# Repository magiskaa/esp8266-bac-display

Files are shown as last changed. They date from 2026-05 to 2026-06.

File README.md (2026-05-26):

# ESP8266 BAC Display

This displays the BAC of a chosen user from the [telegram bot](https://github.com/magiskaa/telegram-bot). It can also add a drink in the [telegram bot](https://github.com/magiskaa/telegram-bot) with a button.

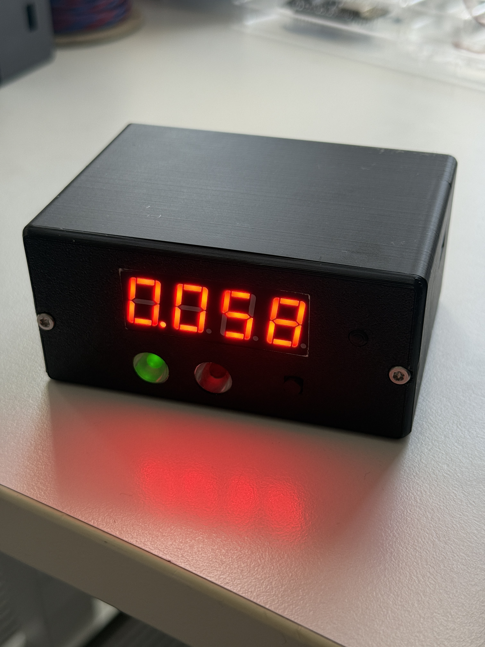
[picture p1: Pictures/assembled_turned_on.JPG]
BAC Display


## Hardware

- Microcontrollers (ESP8266MOD 12-F and Arduino Nano)
- 4-digit 7-segment display
- A green and a red LED
- Two 220Ω resistors
- 4-pin pushbutton
- Jumper wires
- 3D-printed case
- Two M3 threaded inserts and two M3x10 screws

Wiring references:

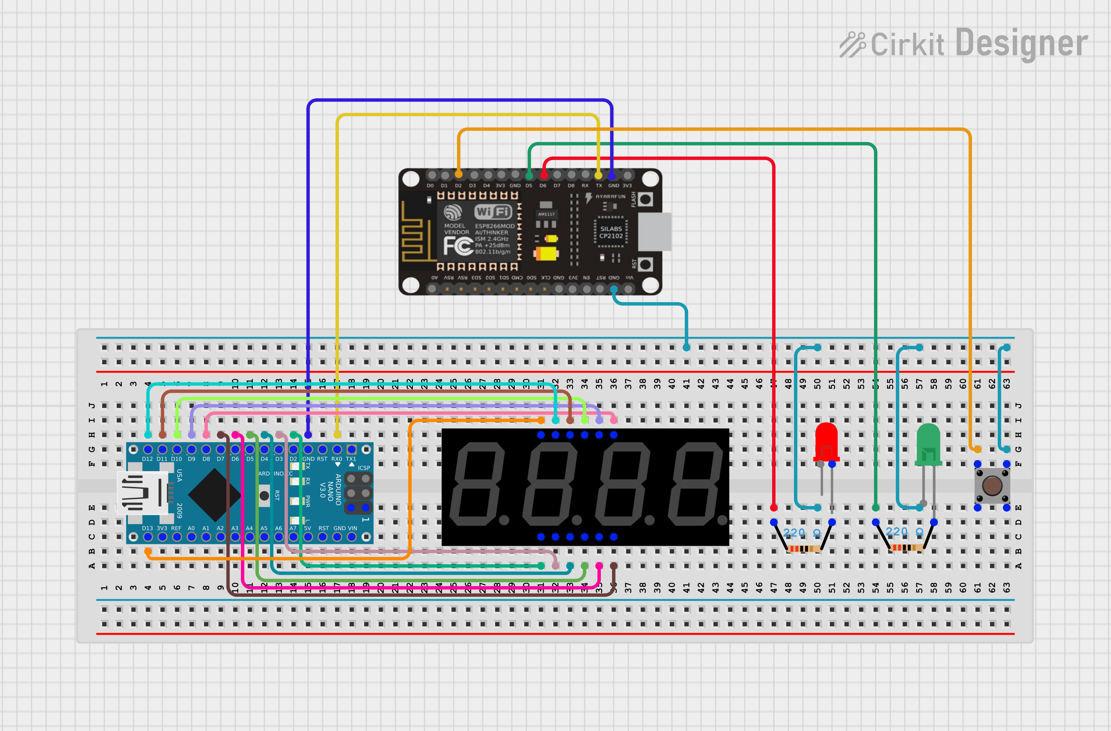
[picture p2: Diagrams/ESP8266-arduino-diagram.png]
ESP8266 BAC Display
- ESP8266 & Arduino Nano & 7-segment display 

## secrets.h

Path to secrets-file: `Sketches/secrets.h`

```cpp
#ifndef SECRETS_H
#define SECRETS_H

const char* SSID = "WIFI_SSID";
const char* PASSWORD = "WIFI_PASSWORD";

const char* SERVER_NAME_BAC = "http://IP_ADDRESS:PORT/PATH";
const char* SERVER_NAME_DRINK = "http://IP_ADDRESS:PORT/PATH";

const char* USER_ID = "TELEGRAM_USER_ID";

#endif
```

## License

This project is licensed under the MIT License (see `LICENSE`).

## Contact

**Valtteri Antikainen**
vantikaine@gmail.com

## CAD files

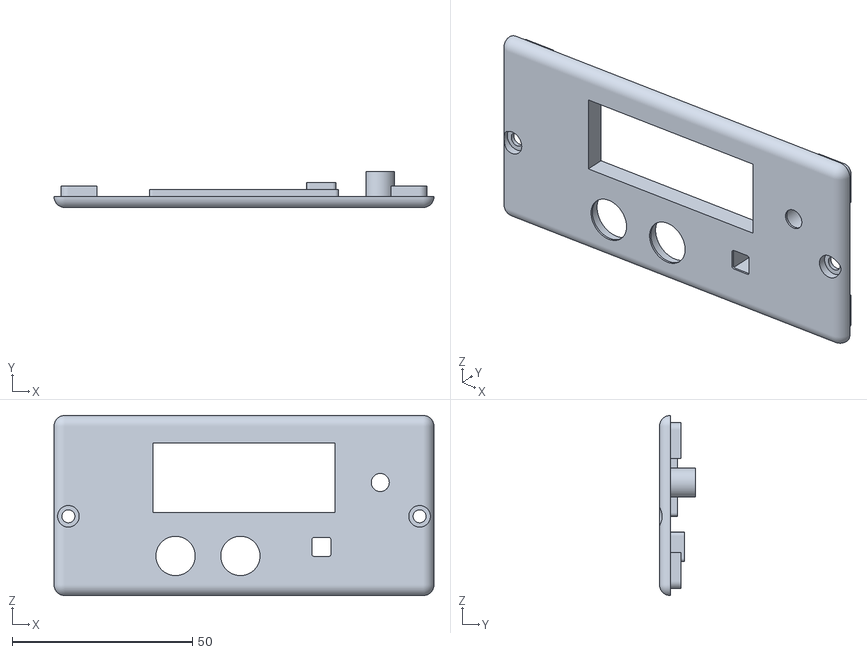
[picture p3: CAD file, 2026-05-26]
3D-models/STL-files/lid.stl
105.5 x 10.0 x 50.0

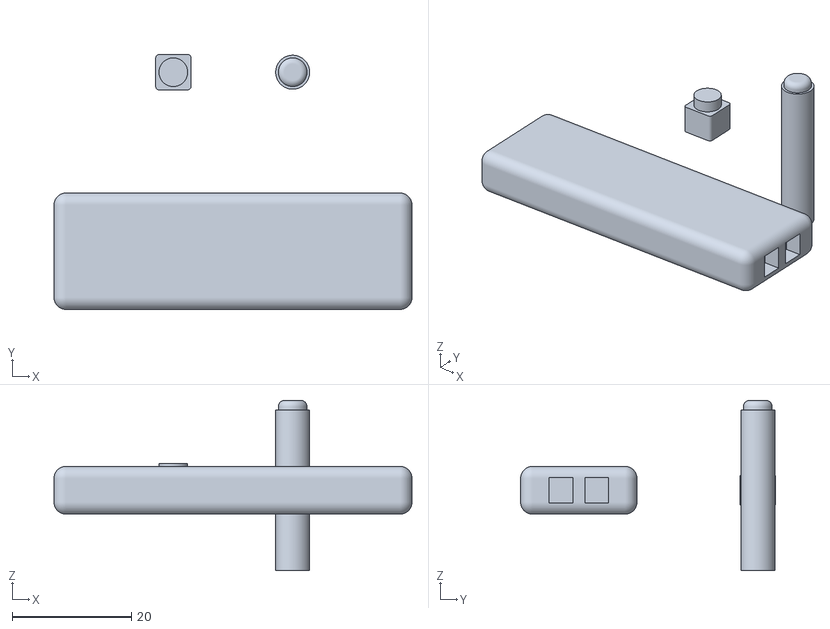
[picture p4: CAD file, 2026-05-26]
3D-models/STL-files/button_rods.stl
60.0 x 42.7 x 28.5

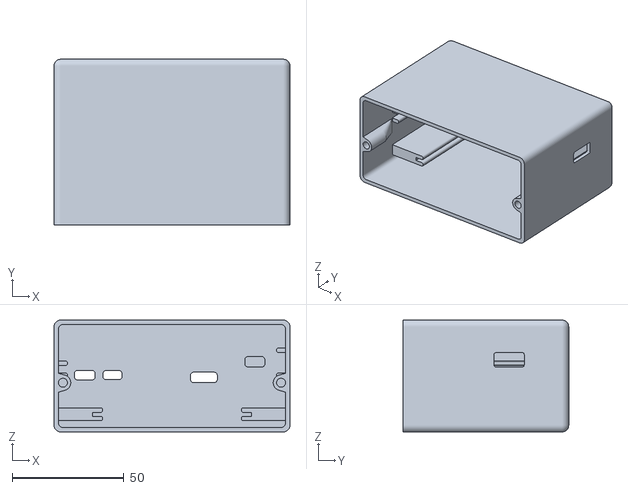
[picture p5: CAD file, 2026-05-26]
3D-models/STL-files/case.stl
105.5 x 74.0 x 50.0

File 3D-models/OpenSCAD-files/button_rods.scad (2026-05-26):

include <BOSL2/std.scad>

rod_r = 2.4;
rod_side = 6.1 - 0.2;
rod_h = 5;

pwr_rod_r = 2.85;
pwr_rod_h = 26.9;
pwr_rod_r_small = 2.4;


$fn = 100;

left(10)
cuboid([rod_side, rod_side, rod_h], rounding = 0.5, edges = "Z") {
	position(TOP) zcyl(r = rod_r, h = 2, anchor = BOTTOM);
}

right(10)
zcyl(r = pwr_rod_r, h = pwr_rod_h) {
	position(TOP) zcyl(r = pwr_rod_r_small, h = 1.6, anchor = BOTTOM, rounding2 = 1);
}

diff() {
	fwd(30)
	cuboid([60, 19.5, 8], rounding = 2) {
		yflip_copy(offset = 0)
		tag("remove") position(RIGHT) fwd(3) cuboid([6, 4, 4.2]);
	}
}

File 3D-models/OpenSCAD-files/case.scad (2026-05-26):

include <BOSL2/std.scad>

wall_t = 2;

w = 101.5;
d = 72;
h = 46;

$fn = 100;

diff() {
	cuboid([w + 2*wall_t, d + wall_t, h + 2*wall_t], rounding = 3, edges = ["Y", BACK]) {
		tag("remove") fwd(wall_t / 2 + 0.001) cuboid([w, d, h], rounding = 2, edges = "Y");
		
		// USB PORT
		up(h / 2 - 21.6 + 9) back((d-wall_t) / 2 - 17.9)
		tag("remove") position(RIGHT) cuboid([5, 13.5, 6.3], anchor = TOP+BACK, rounding = 0.75, edges = "X");
		
		up(h / 2 - 21.6 + 2.6) right(w / 2 - 9.2) fwd(3)
		tag("remove") position(BACK) cuboid([9, 5, 4.7], anchor = BOTTOM+RIGHT, rounding = 1.5, edges = "Y");

		// BATTERY CHARGE INDICATOR
		up(h / 2 - 21.6 + 2.8 - 7.2) right(w / 2 - 30.5)
		tag("remove") position(BACK) cuboid([12, 5, 4.7], anchor = BOTTOM+RIGHT, rounding = 1.5, edges = "Y");
		
		// BATTERY SHIELD PORTS
		up(h / 2 - 21.6 + 1.1) left(w / 2 - 7.1)
		tag("remove") position(BACK) cuboid([9.3, 5, 4.3], anchor = TOP+LEFT, rounding = 1.5, edges = "Y");
		
		up(h / 2 - 21.6 + 1) left(w / 2 - 19.8)
		tag("remove") position(BACK) cuboid([8.7, 5, 4], anchor = TOP+LEFT, rounding = 1.5, edges = "Y");
		
		// ESP & ARDUINO PORTS
//		down(h / 2 - 5 - 6.6) left(70 / 2 - 22.3)
//		tag("remove") position(BACK) cuboid([8.7, 5, 4], rounding = 1.5, edges = "Y");
//		
//		down(h / 2 - 5 - 6.6 - 1.5) right(70 / 2 - 16)
//		tag("remove") position(BACK) cuboid([9.3, 5, 4.3], rounding = 1.5, edges = "Y");
	}	
}

xflip_copy(offset = 0)
right(w/2-wall_t) fwd((d+wall_t)/2-6) down(3)
diff() {
	hull() {
		ycyl(r = 3.5, h = 12);
		
		right(3.5) back(7) cuboid([1, 26, 9]);
	}
	
	tag("remove") ycyl(r = 2, h = 12.01);
}

// BATTERY

xflip_copy(offset = 0)
up(h / 2 - 21.6) left(w / 2) back((d-wall_t) / 2)
cuboid([4, 48, 2], anchor = TOP+LEFT+BACK, rounding = 0.8, edges = RIGHT, except = [BACK, FRONT]);

up(h / 2 - 21.6 + 3.3) left(w / 2) back((d-wall_t) / 2)
cuboid([4, 48, 2], anchor = BOTTOM+LEFT+BACK, rounding = 0.8, edges = RIGHT, except = [BACK, FRONT]);

up(h / 2 - 21.6 + 9.1) right(w / 2) back((d-wall_t) / 2)
cuboid([4, 48, 2], anchor = BOTTOM+RIGHT+BACK, rounding = 0.8, edges = LEFT, except = [BACK, FRONT]);


// ESP & ARDUINO

xflip_copy(offset = 0)
down(h / 2 - 5) left(w / 2) back((d-wall_t) / 2)
cuboid([(w - 70) / 2 + 4, 48, 2], anchor = TOP+LEFT+BACK, rounding = 0.8, edges = RIGHT, except = [BACK, FRONT]);

xflip_copy(offset = 0)
down(h / 2 - 5 - 1.75) left(w / 2) back((d-wall_t) / 2)
cuboid([(w - 70) / 2 + 4, 48, 2], anchor = BOTTOM+LEFT+BACK, rounding = 0.8, edges = RIGHT, except = [BACK, FRONT]);

xflip_copy(offset = 0)
down(h / 2 - 5 - 2) left(w / 2) back((d-wall_t) / 2)
cuboid([(w - 70) / 2 - 0.5, 48, 3], anchor = TOP+LEFT+BACK);

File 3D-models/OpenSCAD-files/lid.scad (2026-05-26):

include <BOSL2/std.scad>

wall_t = 2;

w = 101.5;
d = 3;
h = 46;

display_w = 50.6;
display_d = 10;
display_h = 19.3;

led_d = 11.9;
led_r = led_d / 2;

button_side = 6.2;

screw_r = 1.8;
screw_head_r = 3;

pwr_btn_r = 3;

$fn = 100;

diff() {
	cuboid([w + 2*wall_t, d, h + 2*wall_t], anchor = BOTTOM, rounding = 3, edges = ["Y", FRONT]) {
		down(3) fwd(d / 2) cuboid([display_w + 2, 5, display_h + 2], anchor = BOTTOM+FRONT, rounding = 1, edges = "Y");
		tag("remove") down(2) back(2) cuboid([display_w, display_d, display_h], anchor = BOTTOM);
		
		tag("remove") down(2 + 12) left(19) back(0.5) ycyl(r = led_r, h = d);
		tag("remove") down(2 + 12) left(19) ycyl(r = led_r - 0.5, h = d, anchor = BACK);
		
		tag("remove") down(2 + 12) left(1) back(0.5) ycyl(r = led_r, h = d);
		tag("remove") down(2 + 12) left(1) ycyl(r = led_r - 0.5, h = d, anchor = BACK);
		
		tag("remove") down(2 + 9.5) right(21.5) fwd(1) cuboid([button_side, 10, button_side], anchor = FRONT);
		tag("remove") down(2 + 9.5) right(21.5) cuboid([button_side - 1, d, button_side - 1], anchor = BACK, rounding = 0.5, edges = "Y");
		down(2 + 9.5) fwd(d / 2) right(21.5) cuboid([button_side + 2, 7, button_side + 2], anchor = FRONT, rounding = 1, edges = "Y");
		
		xflip_copy(offset = 0)
		tag("remove") right(w / 2 - wall_t) down(3) ycyl(r = screw_r, h = 10);
		xflip_copy(offset = 0)
		tag("remove") right(w / 2 - wall_t) fwd(0.5) down(3) ycyl(r = screw_head_r, h = 2.01);
		
		right(w / 2 - 10.8 + 0.7) up(h / 2 - 14.5 + 0.7) back(1.5) ycyl(r = pwr_btn_r + 1, h = 7, anchor = FRONT+TOP+RIGHT);
		tag("remove") right(w / 2 - 10.8) up(h / 2 - 14.5) fwd(1) ycyl(r = pwr_btn_r, h = 20, anchor = FRONT+TOP+RIGHT);
		tag("remove") right(w / 2 - 10.8 - 0.35) up(h / 2 - 14.5 - 0.35) ycyl(r = pwr_btn_r - 0.5, h = 20, anchor = TOP+RIGHT);
	}	
}

diff() {
	up(wall_t) back(d)
	cuboid([w, d, h], anchor = BOTTOM, rounding = 2, edges = "Y") {
		tag("remove") cuboid([w - 2, 10, h - 2], rounding = 2, edges = "Y");
		tag("remove") cuboid([w + 10, 10, h - 20]);
		tag("remove") cuboid([w - 20, 10, h + 10]);
	}
}

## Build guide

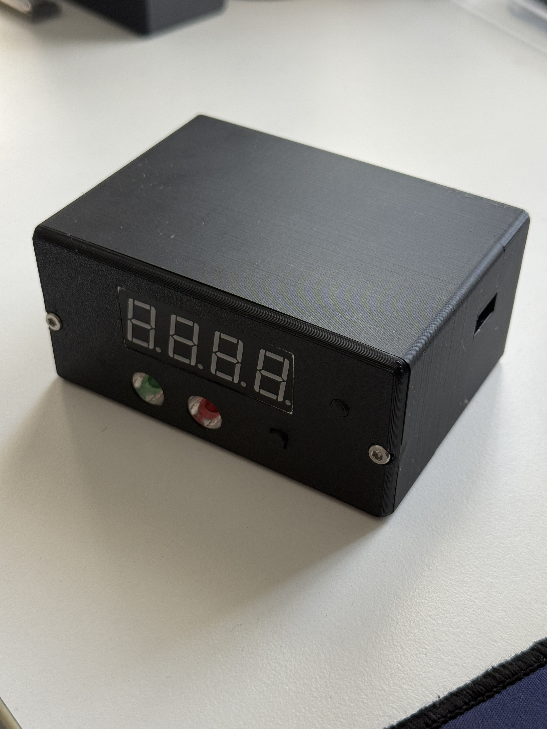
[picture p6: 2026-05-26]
Pictures/assembled.JPG

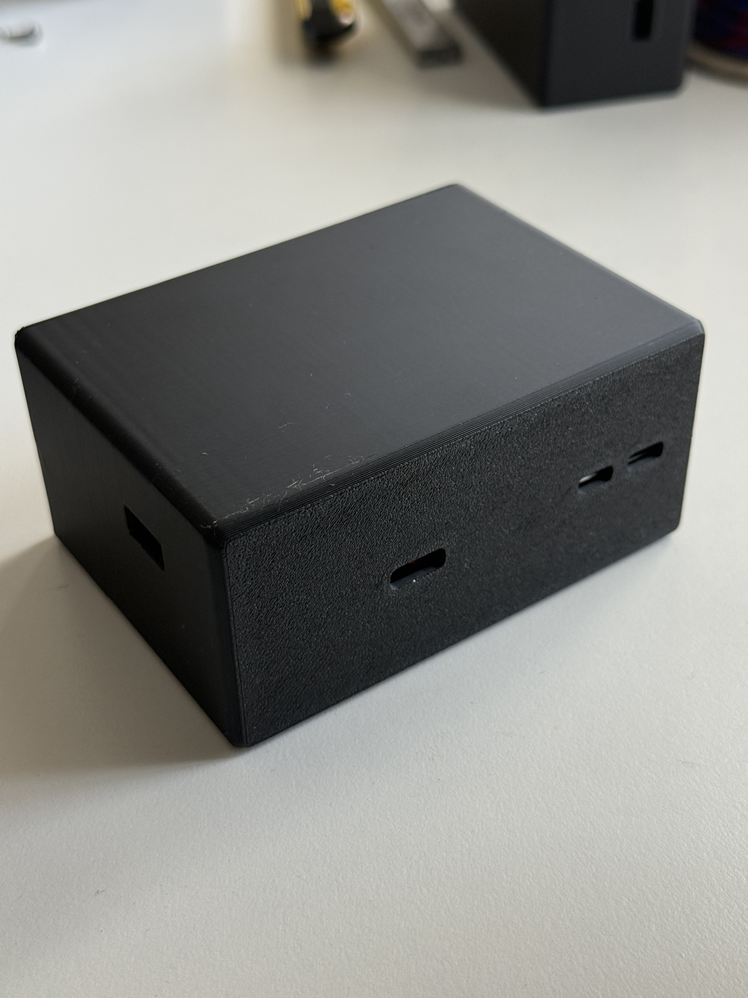
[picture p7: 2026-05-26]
Pictures/assembled_backside.JPG

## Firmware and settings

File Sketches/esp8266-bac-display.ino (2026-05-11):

#include <ESP8266WiFi.h>
#include <ESP8266HTTPClient.h>
#include <Arduino_JSON.h>
#include "secrets.h"

#define GREEN 14
#define RED 12

float bac = 0.0;
float previous = 0.0;
bool initialized = false;
int bac_rounded_int;

void setup() {
  Serial.begin(9600);
  
  WiFi.begin(SSID, PASSWORD);
  WiFi.setSleep(false);
  WiFi.setAutoReconnect(true);

  while (WiFi.status() != WL_CONNECTED) {
    delay(500);
    Serial.print(".");
  }
  Serial.println(WiFi.localIP());

  pinMode(GREEN, OUTPUT);
  digitalWrite(GREEN, LOW);
  pinMode(RED, OUTPUT);
  digitalWrite(RED, LOW);
}

void loop() {
  if (WiFi.status() == WL_CONNECTED) {
    String url = String(SERVER_NAME) + "?id=" + USER_ID;
    String s = httpGETRequest(url);
    s.trim();
    bac = s.toFloat();
  }

  bac_rounded_int = (int)(bac * 1000.0 + 0.5);
  char buf[6];
  snprintf(buf, sizeof(buf), "%04d", bac_rounded_int);
  Serial.println(buf);
  
  if (!initialized) {
    previous = bac;
    initialized = true;
  } else {
    if (previous < bac) {
      digitalWrite(GREEN, HIGH);
      digitalWrite(RED, LOW);
    } else if (previous > bac) {
      digitalWrite(GREEN, LOW);
      digitalWrite(RED, HIGH);
    }
    previous = bac;
  }

  delay(1000);
}

String httpGETRequest(const String& url) {
  WiFiClient client;
  HTTPClient http;

  http.setReuse(false);
  http.setTimeout(4000);

  if (!http.begin(client, url)) {
    return "";
  }

  int httpResponseCode = http.GET();

  String payload = "";
  if (httpResponseCode > 0) {
    payload = http.getString();
  } else {
    Serial.printf(
      "GET %s => %d (%s)\n",
      url.c_str(),
      httpResponseCode,
      http.errorToString(httpResponseCode).c_str()
    );
  }

  http.end();
  return payload;
}

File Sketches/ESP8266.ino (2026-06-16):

#include <ESP8266WiFi.h>
#include <ESP8266HTTPClient.h>
#include <Arduino_JSON.h>
#include "secrets.h"

float bac = 0.0;
float previous = 0.0;
int bac_rounded_int;

bool initialized = false;
String res;

unsigned long lastBacFetch = 0;
const unsigned long bacInterval = 15000;

bool stableButtonState = HIGH;
bool lastButtonState = HIGH;

const unsigned long debounceMs = 500;
const unsigned long pressCooldownMs = 5000;

unsigned long lastDebounceTime = 0;
unsigned long lastAcceptedPressTime = 0;

void setup() {
  Serial.begin(9600);
  
  pinMode(GREEN, OUTPUT);
  digitalWrite(GREEN, LOW);
  pinMode(RED, OUTPUT);
  digitalWrite(RED, LOW);
  pinMode(BUTTON, INPUT_PULLUP);
  
  Serial.println("Connecting to wifi...");
  WiFi.begin(SSID, PASSWORD);
  WiFi.setSleep(false);
  WiFi.setAutoReconnect(true);

  while (WiFi.status() != WL_CONNECTED) {
    delay(500);
    Serial.print(".");
  }
  Serial.println(WiFi.localIP());
}

void loop() {
  if (WiFi.status() != WL_CONNECTED) {
    return;
  }
  
  bool buttonState = digitalRead(BUTTON);
  
  /* FOR DEBUGGING
  static bool prevRaw = HIGH;
  if (buttonState != prevRaw) {
    Serial.print("RAW button changed to: ");
    Serial.println(buttonState == LOW ? "LOW" : "HIGH");
    prevRaw = buttonState;
  } */

  if (buttonState != lastButtonState) {
    lastDebounceTime = millis();
  }

  if ((millis() - lastDebounceTime) > debounceMs) {
    if (buttonState != stableButtonState) {
      stableButtonState = buttonState;

      if (stableButtonState == LOW && millis() - lastAcceptedPressTime > pressCooldownMs) {
        Serial.println("ACCEPTED BUTTON PRESS");
        lastAcceptedPressTime = millis();
        updateBac(SERVER_NAME_DRINK);
      }
    }
  }
  lastButtonState = buttonState;

  unsigned long now = millis();
  if (now - lastBacFetch >= bacInterval) {
    lastBacFetch = now;
    updateBac(SERVER_NAME_BAC);
  }
}

void updateBac(const String& serverName) {
  String url = String(serverName) + "?id=" + userId;
  String res = httpGETRequest(url);
  res.trim();
  
  bac = res.toFloat();
  bac_rounded_int = (int)(bac * 1000.0 + 0.5);
  
  char buf[6];
  snprintf(buf, sizeof(buf), "%04d", bac_rounded_int);
  Serial.println(buf);
  
  if (!initialized) {
    previous = bac;
    initialized = true;
  } else {
    if (previous < bac) {
      digitalWrite(GREEN, HIGH);
      digitalWrite(RED, LOW);
    } else if (previous > bac) {
      digitalWrite(GREEN, LOW);
      digitalWrite(RED, HIGH);
    }
    previous = bac;
  }
}

String httpGETRequest(const String& url) {
  WiFiClient client;
  HTTPClient http;

  http.setReuse(false);
  http.setTimeout(4000);

  if (!http.begin(client, url)) {
    return "";
  }

  int httpResponseCode = http.GET();

  String payload = "";
  if (httpResponseCode > 0) {
    payload = http.getString();
  } else {
    Serial.printf(
      "GET %s => %d (%s)\n",
      url.c_str(),
      httpResponseCode,
      http.errorToString(httpResponseCode).c_str()
    );
  }

  http.end();
  return payload;
}

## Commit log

2026-05-26 Finished ESP8266 bac display project
    [button_rods.scad, button_rods.stl, case.scad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]
2026-06-16 Added a debounce and a cooldown to the button
